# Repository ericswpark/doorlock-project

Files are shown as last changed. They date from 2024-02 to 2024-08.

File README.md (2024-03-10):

# Doorlock Project

Watch the video here: https://youtu.be/iYCekzGeNBQ

You will have to modify the FreeCAD files to match your door frame and lock dimensions.

# Acknowledgements

Thanks to the members of the FreeCAD forums for the help on modeling the parts!

- https://forum.freecad.org/viewtopic.php?p=719558
- https://forum.freecad.org/viewtopic.php?p=721060

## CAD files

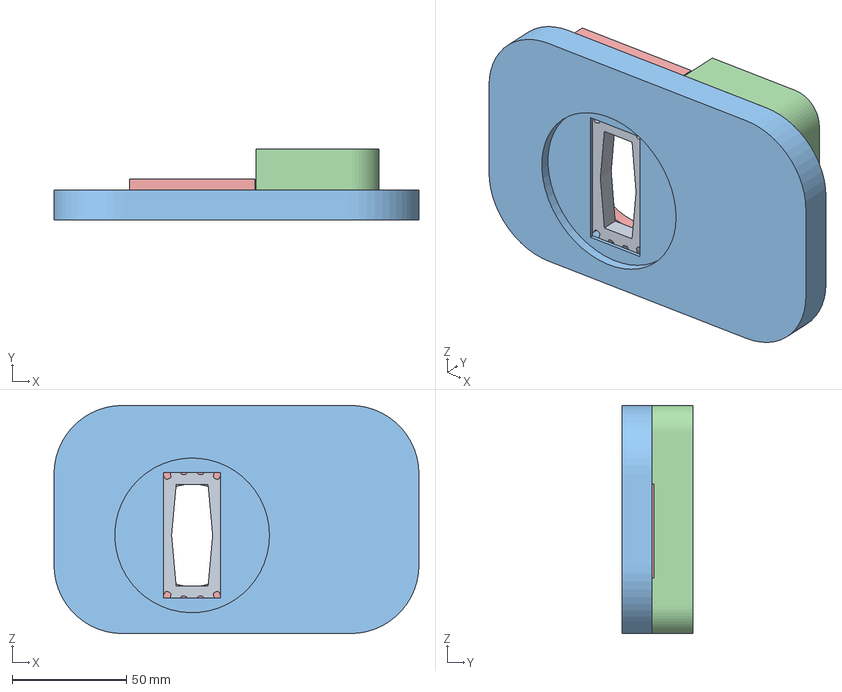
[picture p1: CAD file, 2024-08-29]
enclosure/enclosure.FCStd
160.0 x 31.0 x 100.0 mm
LockGear_Cut
ServoGear_Cut
LockGear_Retention (Meshed)

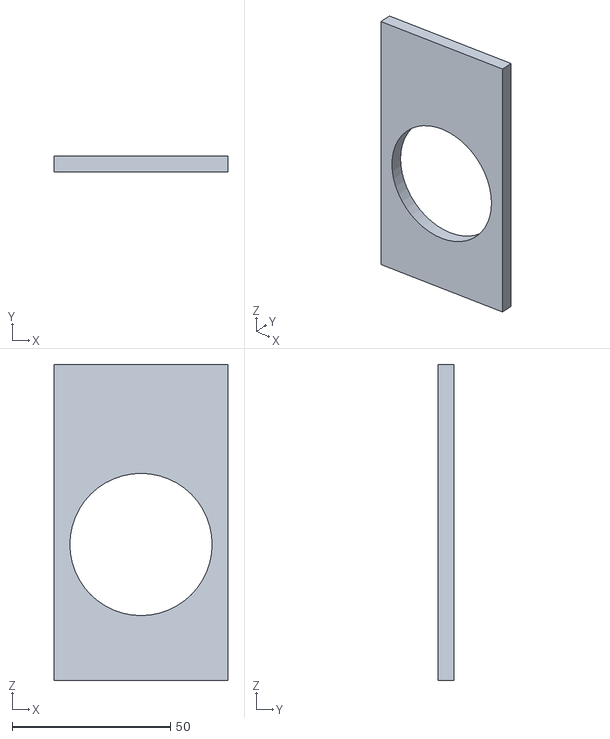
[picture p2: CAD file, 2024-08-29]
enclosure/LockGear_Retention (Meshed).stl
55.0 x 5.00 x 100.0

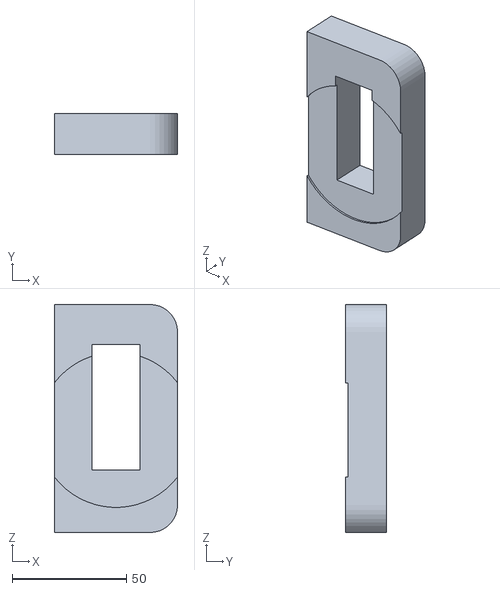
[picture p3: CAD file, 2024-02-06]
enclosure/ServoMount (Meshed).stl
54.0 x 18.0 x 100.0

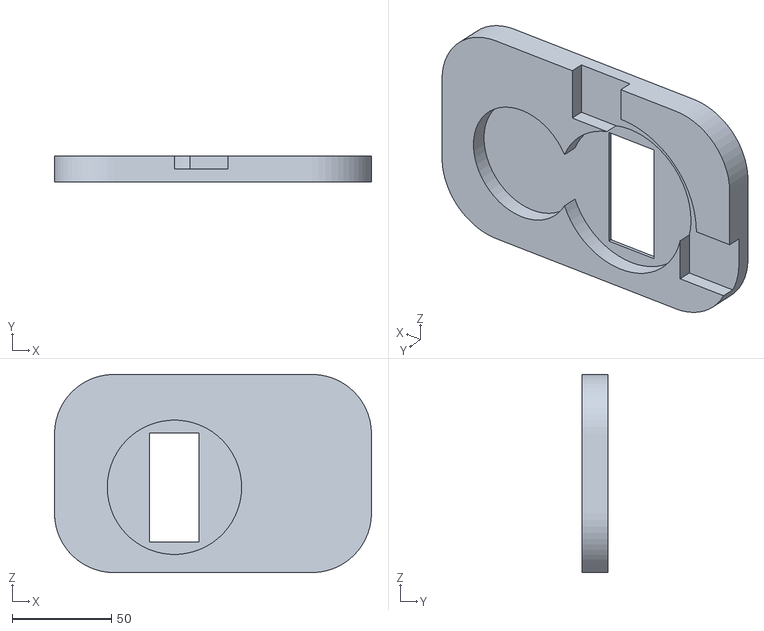
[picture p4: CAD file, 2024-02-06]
enclosure/Enclosure_cut (Meshed).stl
160.0 x 13.0 x 100.0

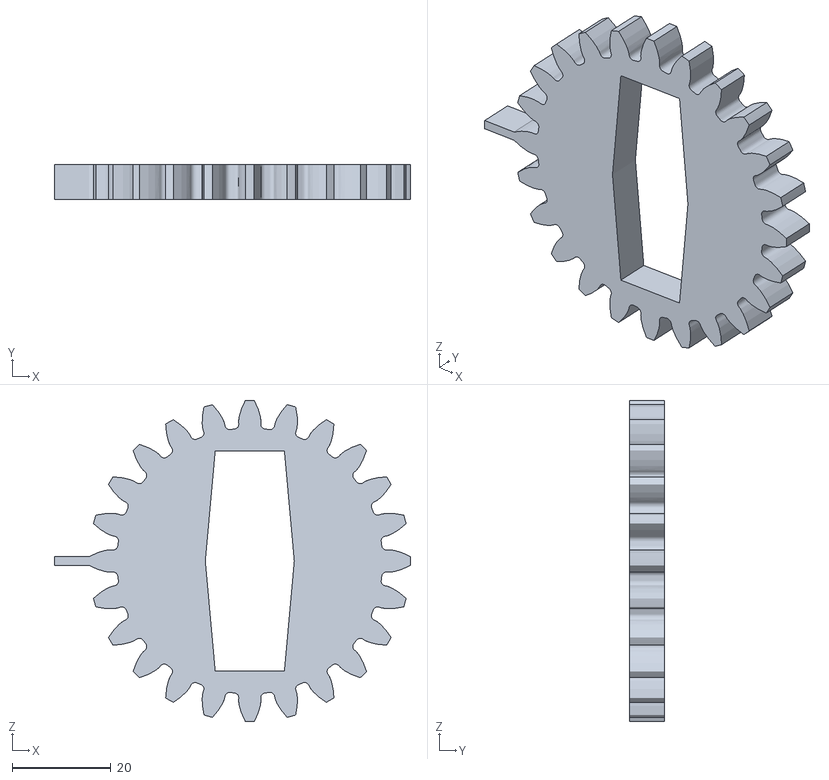
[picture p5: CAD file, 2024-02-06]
enclosure/LockGear_Cut (Meshed).stl
72.0 x 7.00 x 65.0

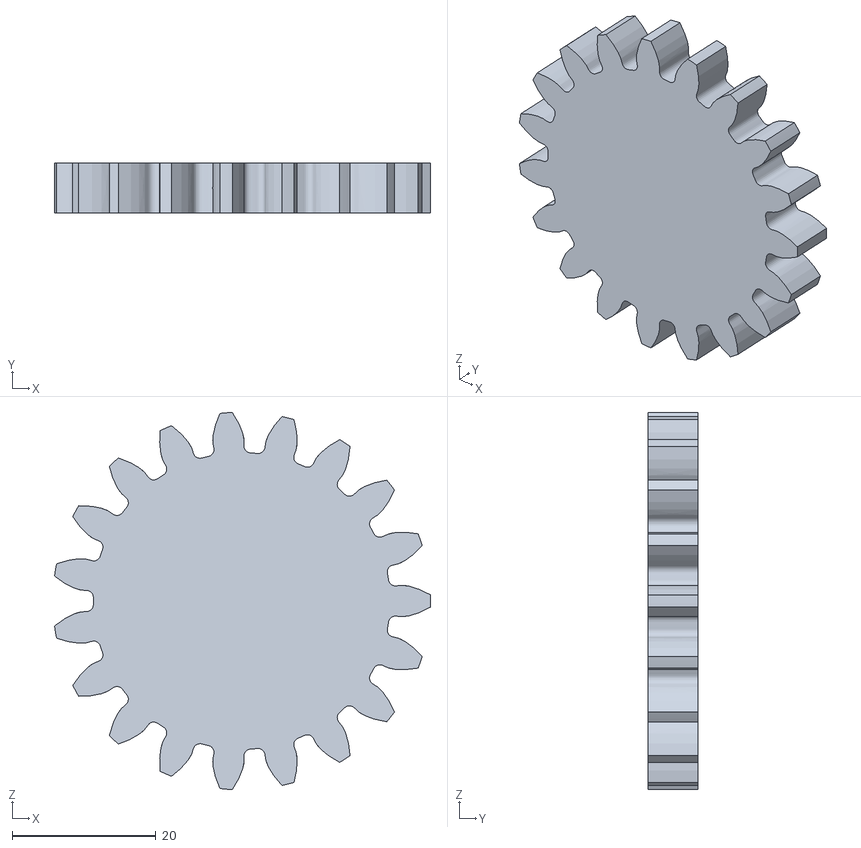
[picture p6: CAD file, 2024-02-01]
enclosure/ServoGear_Cut (Meshed).stl
52.3 x 7.00 x 52.4

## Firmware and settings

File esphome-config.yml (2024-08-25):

esphome:
  name: esphome-web-123456
  friendly_name: bedroom-lock

esp8266:
  board: d1_mini
  restore_from_flash: true

# Enable logging
logger:

# Enable Home Assistant API
api:
  encryption:
    key: !secret bedroom_doorlock_project_api_key

ota:
  platform: esphome
  password: !secret bedroom_doorlock_project_ota_password

wifi:
  ssid: !secret wifi_ssid
  password: !secret wifi_password

  # Enable fallback hotspot (captive portal) in case wifi connection fails
  ap:
    ssid: "esphome-web-123456"
    password: !secret bedroom_doorlock_project_fallback_ap_password

captive_portal:


# Start board config
output:
  - platform: esp8266_pwm
    id: pwm_output
    pin: D7
    frequency: 50Hz

servo:
  - id: lock_servo
    output: pwm_output
    restore: true
    transition_length: 2s
    auto_detach_time: 2s


lock:
  - platform: template
    id: lock_template
    name: "Lock Template"
    icon: "mdi:lock"
    optimistic: true
    lock_action:
      - servo.write:
          id: lock_servo
          level: !lambda return id(locked_servo_position).state;
    unlock_action:
      - servo.write:
          id: lock_servo
          level: !lambda return id(unlocked_servo_position).state;

binary_sensor:
  - platform: gpio
    name: "Switch"
    id: push_button
    on_press:
      then:
        lambda: |-
          if (id(lock_template).state == LOCK_STATE_LOCKED ) {
            id(lock_template).unlock();
          } else {
            id(lock_template).lock();
          }
    pin:
      number: D1
      inverted: true
      mode:
        input: true
        pullup: true


number:
  - platform: template
    name: Locked servo position
    id: locked_servo_position
    entity_category: config
    min_value: -1
    max_value: 1
    initial_value: -0.7
    optimistic: true
    step: 0.1
    restore_value: true
    mode: slider
  - platform: template
    name: Unlocked servo position
    id: unlocked_servo_position
    entity_category: config
    min_value: -1
    max_value: 1
    initial_value: 0.8
    optimistic: true
    step: 0.1
    restore_value: true
    mode: slider
  - platform: template
    name: Transition Length (sec)
    id: servo_transition_length
    entity_category: config
    min_value: 0
    max_value: 5
    initial_value: 2
    optimistic: true
    step: 0.1
    restore_value: true
    mode: box
    set_action:
      lambda: |-
        return id(lock_servo).set_transition_length(x * 1000);
  - platform: template
    name: Auto Detach Time (sec)
    id: servo_auto_detach_time
    entity_category: config
    min_value: 0
    max_value: 5
    initial_value: 2
    optimistic: true
    step: 0.1
    restore_value: true
    mode: box
    set_action:
      lambda: |-
        return id(lock_servo).set_auto_detach_time(x * 1000);

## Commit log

2023-11-25 Initial commit
    Finished creating initial FreeCAD file with models for door lock and
    servo
    [enclosure.FCStd]
2023-11-25 Finish modeling all parts
    Still need to boolean cut out the servo horn and lock from the connector
    [enclosure.FCStd]
2023-11-25 Final design
    [enclosure.FCStd]
2023-11-25 Export pieces
    [Connector.stl, Enclosure.stl, enclosure.FCStd]
2023-11-27 Reduce enclosure height
    Save some filament
    [enclosure.FCStd]
2023-11-27 Add push button and TP4056 charging board
    [enclosure.FCStd]
2023-11-27 Finish cutting out holes in enclosure
    [enclosure.FCStd]
2023-11-27 Re-export enclosure
    [Enclosure.stl, enclosure.FCStd]
2023-11-28 Increase dimensions of lock
    Lock was significantly bigger than expected and I wasted a 3D print to
    realize that :(
    [Connector.stl, enclosure.FCStd]
2023-11-28 Increase size of servo paddle
    Was also too small to fit as well :(
    At least I caught both issues before asking for a reprint
    [Connector.stl, enclosure.FCStd]
2023-11-29 Increase lock dimensions
    Hopefully this will be the last print needed
    [Connector.stl, enclosure.FCStd]
2023-11-30 Increase servo horn diameter
    Oops, forgot to adjust this
    [Connector.stl, Enclosure.stl, enclosure.FCStd]
2023-12-01 Increase size of servo horn
    5th and hopefully final revision print
    [Connector.stl, enclosure.FCStd]
2024-02-01 Remove connector and enclosure pieces
    Time for a fresh start
    [enclosure.FCStd]
2024-02-01 Remove exported files
    [Connector.stl, Enclosure.stl]
2024-02-01 Update lock dimensions
    [enclosure.FCStd]
2024-02-01 Remove straight-turn horn version of servo
    Not needed
    [enclosure.FCStd]
2024-02-01 Add gears
    [enclosure.FCStd]
2024-02-01 Add cut lockgear
    [enclosure.FCStd]
2024-02-01 Update servo dimensions
    [enclosure.FCStd]
2024-02-01 Align servo with gear
    [enclosure.FCStd]
2024-02-01 Initial enclosure draft
    [enclosure.FCStd]
2024-02-01 Finish initial enclosure base
    [enclosure.FCStd]
2024-02-01 Remove unneeded D1 mini and TP4056
    Not necessary for modelling
    [enclosure.FCStd]
2024-02-01 Finish design
    [enclosure.FCStd]
2024-02-01 Export all meshes
    [Enclosure_cut (Meshed).stl, LockGear_Cut (Meshed).stl, ServoGear_Cut (Meshed).stl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]
2024-02-05 Redesign enclosure and servo mount
    We needed a bit of a spacer between the lock and the gear so that the
    gear wouldn't jam into the space between the lock body and handle.
    While we're add it, add bevels to everything!
    [enclosure.FCStd]
2024-02-05 Reexport changed meshes
    [Enclosure_cut (Meshed).stl, ServoMount (Meshed).stl, enclosure.FCStd]
2024-02-06 Decrease lock and door handle margin
    [enclosure.FCStd]
2024-02-06 Move plate closer to wall by 4 mm
    We forgot about the command strips used to attach the plate, which means
    it can now be 4 mm thinner! Less materials used :)
    [enclosure.FCStd]
2024-02-06 Adjust servo mount dimensions
    Changes:
    - Repositioned closer to base plate
    - Decreased distance between gear and mount tolerance to 1mm
    - Reduced servo hole (was about 4mm too tall)
    [enclosure.FCStd]
2024-02-06 Add limit switch tab to lock gear
    [enclosure.FCStd]
2024-02-06 Re-export changed meshes
    [Enclosure_cut (Meshed).stl, LockGear_Cut (Meshed).stl, ServoMount (Meshed).stl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]
2024-03-03 Move design files into enclosure folder
    [Enclosure_cut (Meshed).stl, LockGear_Cut (Meshed).stl, ServoGear_Cut (Meshed).stl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]
2024-03-03 Add ESPHome sample configuration file
2024-03-03 esphome-config: remove unused servo control template
2024-03-03 esphome-config: increase servo transition time
2024-08-20 fix: update ota config on ESPHome
    A recent change requires you to supply the platform. Add esphome for the original behavior.
    [esphome-config.yml]
2024-08-25 feat: allow adjusting timing values for servo on ESPHome
2024-08-25 fix: remove on_boot param to avoid accidentally getting locked out
    It's possible that the power may cut out while the user is outside of
    the room but doesn't have the keys with them. To prevent them
    from being locked out, don't auto-lock on boot.
    [esphome-config.yml]
2024-08-25 fix: restore_values not working
    The `esp8266` platform doesn't automatically save values to the flash,
    which results in the lock and unlock positions getting reset every time
    the board reboots.
    [esphome-config.yml]
2024-08-25 fix: remove web server component
    This can decrease the stability, and the values are configurable in HA
    anyway.
    [esphome-config.yml]
2024-08-27 fix: remove limit switch trough and placement
    [enclosure.FCStd]
2024-08-29 feat: add LockGear retention plate
    [LockGear_Retention (Meshed).stl, enclosure.FCStd]
2025-02-04 Add sponsor button
